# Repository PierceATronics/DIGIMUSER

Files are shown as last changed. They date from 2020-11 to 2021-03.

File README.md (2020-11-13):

# DIGIMUSER
DIGIMUSER is a digital vocal effect processor "stompbox" that applies a variety of real-time signal processing algorithms to alter the voice of a singer. DIGIMUSER takes a (1/4)" mono jack input from a dynamic microphone and outputs through another (1/4)" cable to an amplifier or to additional audio processing equipment. Since the effects applied by DIGIMUSER are performed digitally on a microcontroller, it can be reprogrammed to implement a wide collection of effecus such as filters, delays, distortions, and spatial effects. A standard bypass stomp button enables and disables the effect, a knob selects the type of applied effect, and a slider controls the intensity of the effect.
 
## Project Team Members
David Pierce Walker-Howell (EE), Luke kennard (COMPE), Danielle Stewart (COMPE), Suaod Alhajry (EE), Angel Martinez (COMPE)

## Contribute to this Project
Here are the guidelines to contribute to the project.

#### Branching
The development process for software or hardware must be done in a seperate branch from **main**. Once a software or hardware component is completed a pull request must be made before merging with **main**. The pull request must reviewed and approved before merging to main. 

Here is how to create a new branch off of main. Please use the following naming format for the branch **[Your_name]_[description_of_branch]**

```
Example

//Creates a new branch called "Pierce_I2S_software_development" off of the "main" branch
git checkout -b Pierce_I2S_software_development main
```

#### GIT workflow
Be sure to keep your branch (and the Repository) up-to-date on your local machine by performing pulls often (i.e. be sure to make a pull of the repo prior to making any new edits or commits). Also make sure to commit changes locally often and push those commits to the Github Repository often as well. Below is the typical workflow to follow

```
//Open a git bash or linux terminal and move to the DIGIMUSER project director

//You hop on your computer to begin working on the DIGIMUSER
//First, make sure to pull the repo

git pull

//Next, make sure you are in your development branch

git branch [THE_BRANCH_YOUR_ARE_DEVELOPING_IN]

//Work on coding and designing like on awesome engineer.

//Now you are at a good saving point, and would like to take a break for the day
//Commit your changes with a nice message about what you added/edited

git commit -m "Reworked the communication code for faster data transfer"

//You also want to save your code to the Github repo. So push those commits to the repo

git push origin [THE_BRANCH_YOU_ARE_DEVELOPING_IN]

```

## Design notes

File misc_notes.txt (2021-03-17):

Electrical:
	- The ADC/DAC saturates when a 160mVpp is applied.

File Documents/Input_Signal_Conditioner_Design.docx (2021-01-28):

Input Signal Conditioner (ISC) Circuit Design

David Pierce Walker-Howell

Created: October 27, 2020

1 Description

The Input Signal Conditioner (ISC) is an amplifier and low-pass filter circuit responsible for conditioning the raw microphone signal from a dynamic microphone to be sampled by an Analog-to-Digital Converter (ADC). The circuit comprises of a DC biasing network, non-inverting amplifier, and a 2nd Order Butterworth active low-pass filter (LPF). Presented is the circuit design and specifications to signal the raw microphone signal to be sampled by the Cirrus Logic Inc. CS5343-CZZ Sigma-Delta ADC.

2 Design

2.1 Sallen-Key Low Pass Filter Design

A lowpass filter is designed to condition the frequency response of the microphone prior to sampling of the ADC. Typically, a lowpass filter is used as an anti-aliasing filter for the ADC to ensure no frequency components greater than the Nyquist frequency (Fs / 2) are sampled (which would result in signal aliasing). However, since the design uses a Sigma-Delta ADC with a digital internal anti-aliasing filter, the filter designed for this board is not specifically targeted for anti-aliasing. The lowpass filter design for the Input Signal Conditioner is primarily to cutoff frequencies outside the expected vocal range of a singer. Thus, the cutoff frequency is set to 15KHz, which is a common cutoff frequency estimate for most dynamic microphones. In this design, a Butterwork Sallen-Key lowpass filter is chosen for a variety of reasons [Discuss those here].

There are two critical parameters to consider for selecting an Op-amp for the Sallen-Key LPF: 1) Gain Bandwidth Product (GBWP), 2) Slew Rate. The closed-loop bandwidth of the amplifier must be at least 100 times greater than the passband (or cutoff) frequency of the filter. Thus, the minimum GBWP is calculated as

GBWP_(min) =100*A*f_c =100*1*15K=1.5MHz

The Slew Rate is related to the internal circuitry of the Op-amp and determines how fast the output voltage or current can change. Ideally, the slew rate, measured in volts per microseconds, should be relatively high. The minimum slew rate is calculated based on the cutoff frequency and peak-to-peak output voltage of the amplifier. The minimum slew rate is calculated as

SR_(min) =2πV_(out-pp) f_c =2π(1.0)(15K)=0.09 V/(μs)

Based on the Op-amp requirements, the Microchip MCP6271 rail-to-rail, single-supply Op-amp is chosen.

Specification | Designator | Value
Filter Type | N/A | Butterworth
Configuration | N/A | Sallen-Key
Order | N | 2
Passband Frequency | Fc | 15KHz
DC Gain | A | 1 V/V
Min. GBWP | GBWP_MIN | 1.5MHz
Min. Slew Rate | SR_MIN | 0.09 V / (us)

The design of the lowpass Sallen-Key filter was generated by the Microchip FilterLab® software. The software provides the 1% tolerance resistance and capacitance values to obtain a realistic, implementable filter design.

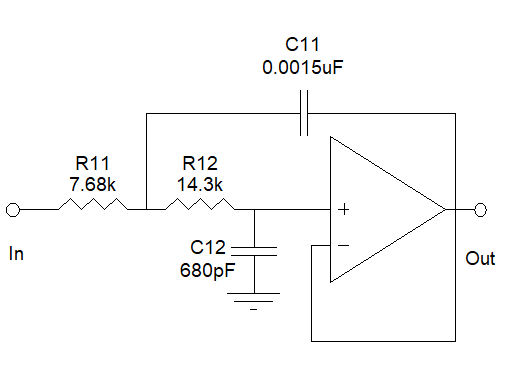
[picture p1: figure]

Figure 1- Sallen-Key, Butterworth, LPF generated by Microchip FilterLab design software (Fc=15KHz).

The designed filter was the simulated in LTSpice with the corresponding MCP6271 Op-amp spice parameters.

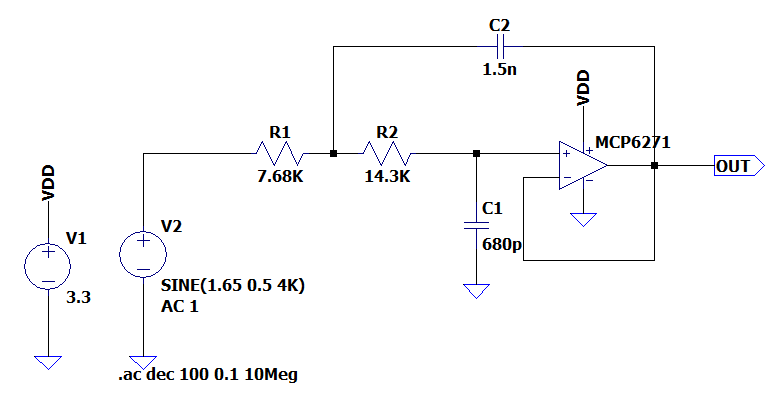
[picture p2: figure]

Figure 2 - LTSpice simulation schematic of LPF.

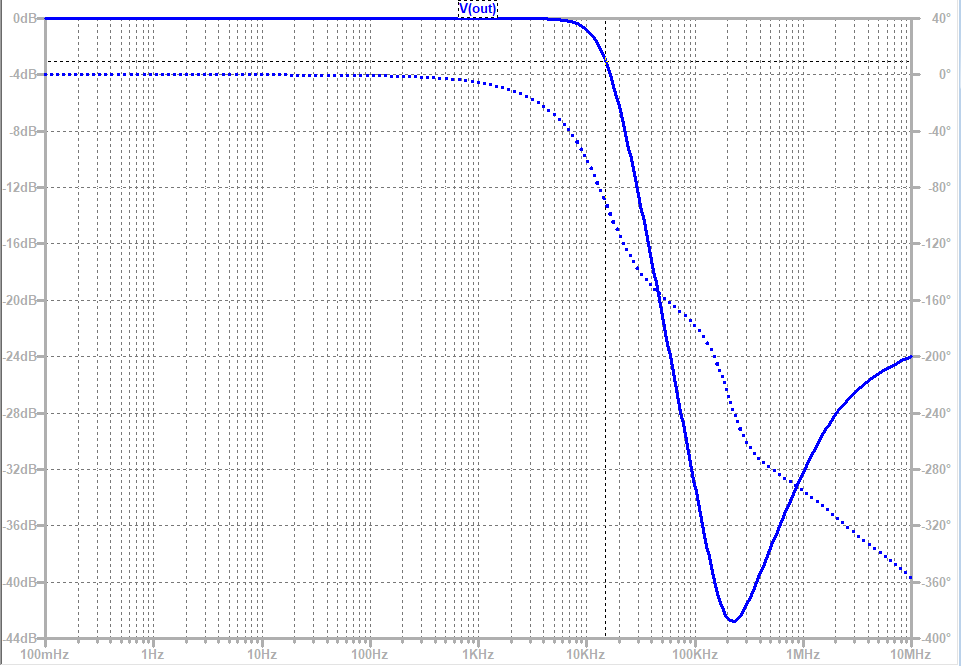
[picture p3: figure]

Figure 3- LTSpice simulated LPF frequency response.

Figure 3 shows the expected magnitude and phase response of the filter. Analyzing the magnitude response shows flat 0dB gain for the passband frequencies and -20dB per decade attenuation after the passband. The expected frequency range of the microphone signal will maintain most of the energy from approximately 50Hz to 2KHz. In this frequency range, it is observed there is a nearly constant group delay (linear phase) as desired.

2.2 Amplifier Design

The raw signal from the microphone is a small signal in the order of tens of millivolts. From initial measurements of a PDMIC58 Pyle Moving Coil Dynamic Handheld Microphone, the maximum raw signal at singing volume is approximately 100mV. This raw signal needs to be amplified and biased for sampling by the ADC.

The ADC chosen is the Cirrus Logic Inc. CS5343-CZZ Sigma-Delta ADC, which provides 24-bit conversion and an internal digital anti-aliasing filter. The datasheet for the device provides suggested analog input signal conditioning. The source impedance (impedance seen from the ADC) should be less than or equal to 2.5KΩ to achieve optimal THD+N performance. The magnitude of the incoming signal to the ADC needs to be less than or equal to the full-scale input voltage of the device. With the ADC operating at 3.3V, the full-scale input voltage range is defined as

V_(fs-pp) =0.568⋅VA=0.568⋅3.3 = 1.874V .

It is important to note the analog input pins of the ADC expects zero DC bias. Thus, the voltage at the input shall be within ±0.937V . The desired gain of the amplifier is calculated as

A_(amp) = (0.937V)/(0.080V)≈12.00V/V=21.6dB

Since the entirety of the design (all PCBs) are powered from a single supply voltage of 3.3V, the analog signal propagating through the Op-amp based amplifier and filter needs to be DC biased to be in the range 0V – 3.3V. Therefore, the input signal of the microphone is DC biased at (V_(DD))/2=1.65V .

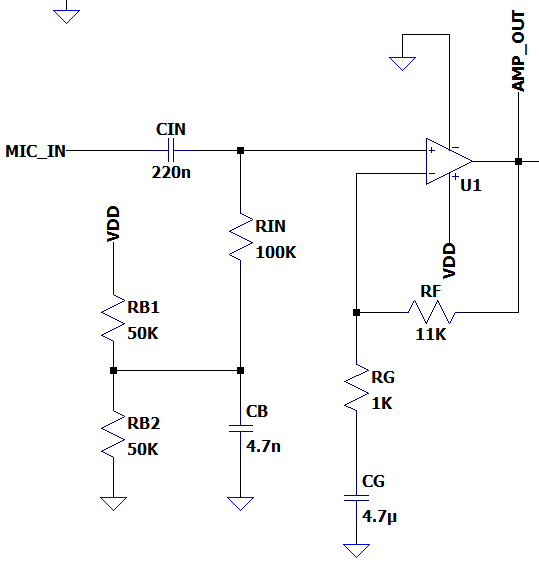
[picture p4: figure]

Figure 4 - Input signal conditioner amplifier

The non-inverting amplifier configuration shown in Figure 4 applies the 1.65V DC bias and amplifies the analog components of the microphone signal by 21.6dB. The input capacitor C_(in) removes any DC components from the raw microphone signal. The DC biasing network composed of R_(B1) ,R_(B2) ,C_b , and R_(in) applies the 1.65V DC bias and acts as a high-pass filter with respect to the microphone input, but a low-pass filter with respect to the V_(DD) input used to set the DC bias value. The primary reason for the addition of C_B is to filter out any analog noise from the power supply of V_(DD) . Ideally, V_(DD) should come from a low-noise voltage regulator and therefore not be of concern. However, if V_(DD) is noisy and not well regulated, the capacitor C_B will filter out any analog frequencies. The AC analysis of the biasing network (with respect to the microphone input) is analyzed to show the frequency response to the incoming microphone signal. A high-pass filter with cutoff-frequency in the tens of volts range is desired since vocal signal are nominally above 80Hz. The network with respect to the microphone input gives the transfer function

H_(bias) (s)=(V_(amp-in+) (s))/(V_(mic-in) (s))=(Z_1 +Z_(3||4))/(Z_1 +Z_2 +Z_(3||4)) .

Z_1 =R_(in) Z_3 =[R_(B1) ||R_(B2) ] Z_4 =1/(C_b s) Z_(3||4) =[Z_3 ||Z_4 ] .

The feedback network of the amplifier, composed of R_f , R_g , and C_g , provides the high passband gain of A_(amp) =12V/V . The capacitor C_g ensures only analog signal components are amplified, and the DC bias signal component is not amplified. The closed-loop transfer function is given as

H_(cl) (s)=(V_(amp-out) (s))/(V_(amp-in) (s))=((R_g +R_f )C_g s + 1)/(R_g C_g s+1)

The total frequency response H_(amp) (s) of the amplifier is given as

H_(amp) (s) = (V_(amp-out) (s))/(V_(mic-in) (s))=H_(bias) (s)H_(cl) (s)

The magnitude frequency response of H_(amp) (s) , with component values shown in Figure 4 , is shown in Figure 5. The cutoff frequency of the amplifier is approximately 35Hz.

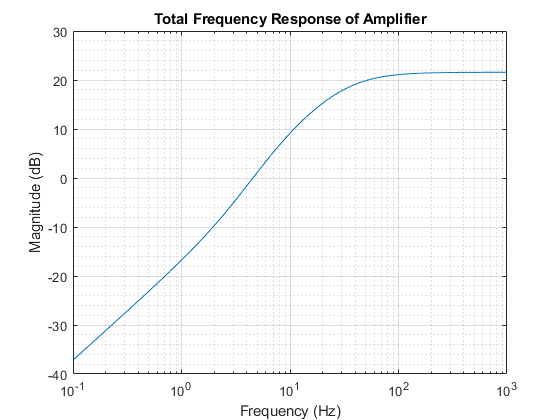
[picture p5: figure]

Figure 5 - Total Frequency response of amplifier

2.3 Combining the Amplifier and Filter

The amplifier and Sallen-key low pass filter are cascaded in series to complete the analog input signal conditioning of the microphone signal for sampling by the ADC. The final design is simulated and verified in LTSpice. It is important to note that the output of the Input Signal Conditioner is at the output of the Sallen-Key lowpass filter. Thus the Input Signal Conditioner does not perform the final step of removing the 1.65V DC bias before feeding into the ADC. This required step is done on the external board hosting the ADC. Therefore, the output of the Input Signal Conditioner is an amplified and low pass filtered version of the microphone signal with 1.65V DC bias.

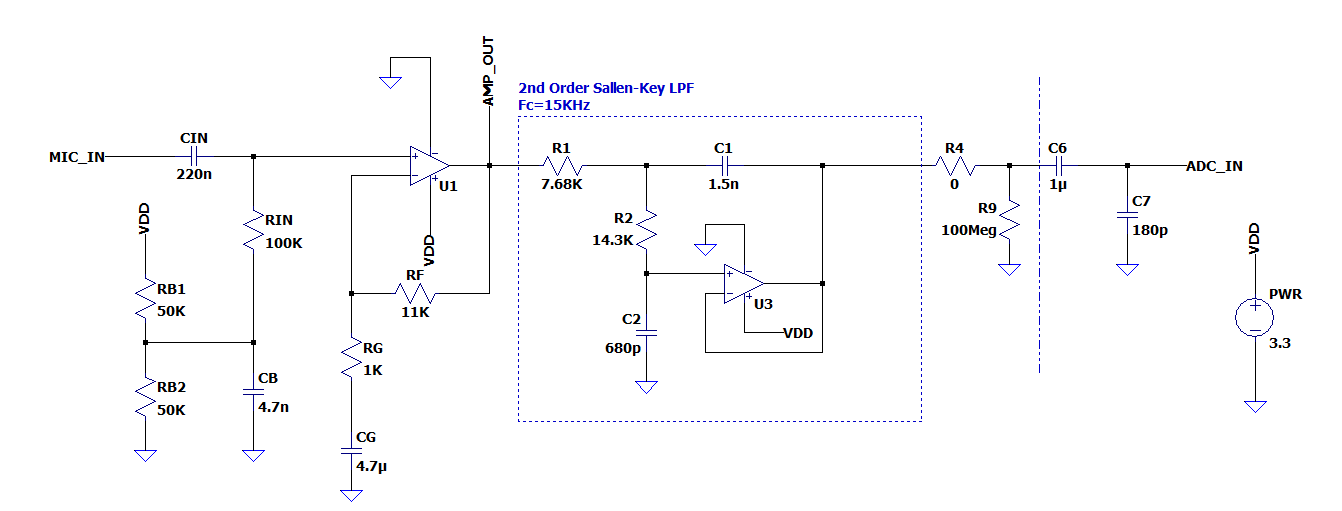
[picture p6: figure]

Figure 6 - Input signal conditioner (Amplifier + LPF) LTSpice schematic.

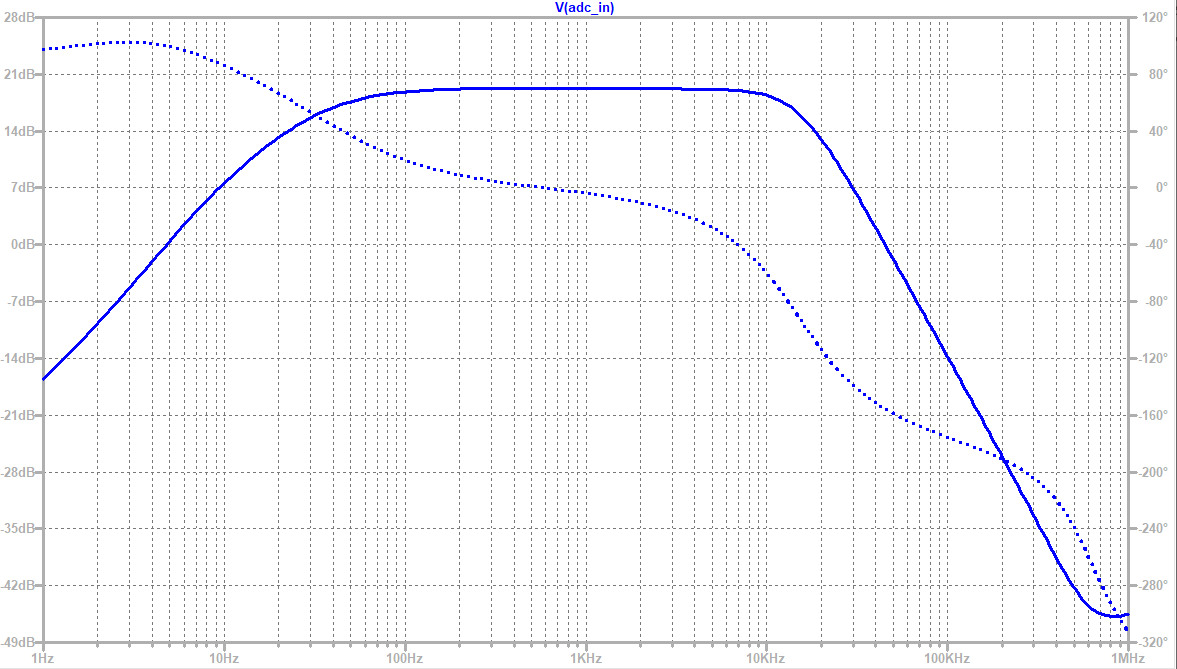
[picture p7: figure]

Figure 7- Frequency response (AC analysis) of Input Signal Conditioner.

Figure 7 is the simulated (expected) frequency response of the Input Signal Conditioner board design. Table 1 summarizes the specifications of the design.

Specification | Designator | Value (Typ.)
Low Freq. Cutoff | Fcl | 35Hz
High Freq. Cutoff | Fch | 15KHz
Passband Gain | A | 21dB
Output DC bias | VDC | 1.65V

Table 1- Input Signal Conditioner Specifications

Prototype

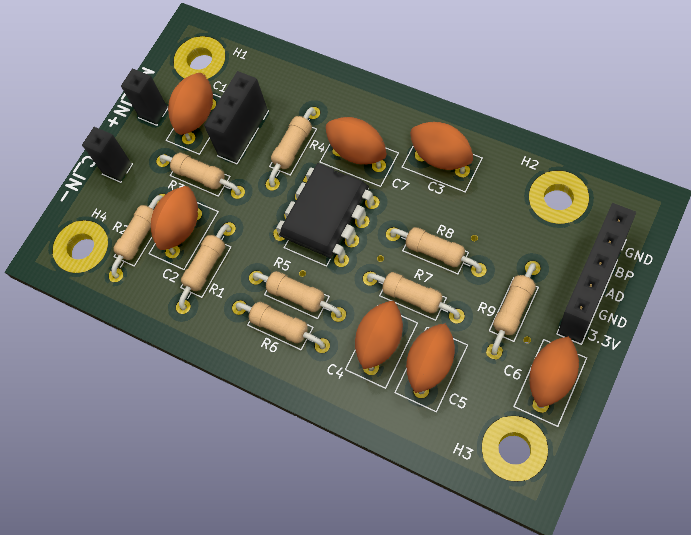
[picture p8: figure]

Figure 8 - PCB design of ISC using KiCad.

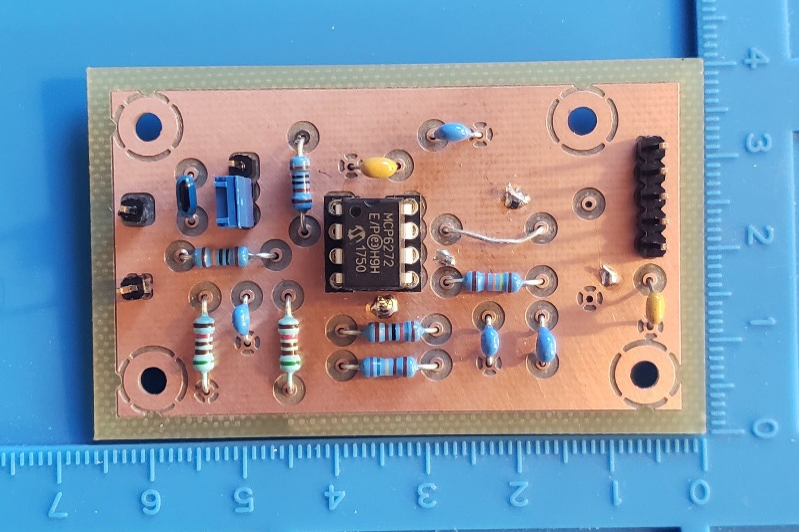
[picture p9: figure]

Figure 9 - Milled and Assembled prototype of the ISC.

Validations

Specification | Designator | Value (Typ.) | Specification Met
Low Freq. Cutoff | Fcl | 35Hz | YES
High Freq. Cutoff | Fch | 15KHz | YES
Passband Gain | A | 21.6 dB | YES – 21.6 dB
Output DC bias | VDC | 1.65V | YES

Validations of the ISC were performed using a function generator for the input signal and an oscilloscope for measuring the output signal. The input signal is a 25mV amplitude sine wave with 0V DC bias. The frequency of the signal was varied to validate the frequency response of the circuit. The input signal matches the approximate expected microphone signal in amplitude.

The oscilloscope plots below present the AC coupled input and output signals of the ISC. The input signal on the ISC is measured at 20mV / div and the output signal is measured at 200 mV / div.

Figure 10 - 100Hz sine wave input (Yellow). The output signal (Blue) has an amplitude of 520mV. The gain at 100Hz is thus A=10.4 V/V.

Figure 11 - 440Hz sine wave input (Yellow). The output signal (Blue) has an amplitude of 610mV. The gain at 440Hz is thus A=12.2V/V.

Figure 12 -1KHz sine wave input (Yellow). The output signal (Blue) has an amplitude of 600mV. The gain at 1KHz is thus A=12.0V/V.

Figure 13- 15KHz sine wave input (Yellow). The output signal (Blue) has an amplitude of 450mV. The gain at 15KHz is thus A=9V/V. 15KHz is the desired -3dB cutoff for this filter circuit, thus that figure is approximately met with a measured -2.5dB attenuation at 15KHz.

Figure 14 - 20KHz sine wave input (Yellow). The output signal (Blue) has an amplitude of 300mV. The gain at 20KHz is thus A=6.0V/V.

Figure 15 - 40KHz sine wave input (Yellow). The output signal (Blue) has an amplitude of 110mV. The gain at 40KHz is thus A=2.2V/V.

Citations

ADN003 “Select the Right Operational Amplifier for your Filtering Circuits”, Bonnie C. Baker, Microchip Technology Inc.

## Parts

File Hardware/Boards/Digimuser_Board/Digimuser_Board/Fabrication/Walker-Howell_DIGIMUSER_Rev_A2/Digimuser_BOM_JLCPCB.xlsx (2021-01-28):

Comment | Designator | Footprint | LCSC Part #（optional）
22nF | C1 | 0805_C | C1729 | x
51KΩ | R1, R2 | 0805_R | C17737 | x
100KΩ | R6 | 0805_R | C17407 | x
4.7nF | C2 | 0805_C | C1744 | x
4.7uF | C3 | 0805_C | C1779 | x
1KΩ | R9 | 0805_R | C17513 | x
11KΩ | R10 | 0805_R | C17429 | x
100nF | C4, C10, C11, C14, C15, C16, C23 | 0805_C | C49678 | x
7.68KΩ | R11 | 0805_R | C30041 | x
14.3KΩ | R12 | 0805_R | C17456 | x
680pF | C5 | 0805_C | C53150 | x
1.5nF | C6 | 0805_C | C1717 | x
10KΩ | R3, R4, R5, R7, R8, R15, R16, R17 | 0805_R | C17414 | x
1uF | C8, C18, C19, C20, C21, C26 | 0805_C | C28323 | x
180pF | C17, C27 | 0805_C | C62914 | x
3.3uF | C7, C9, C12 | 0805_C | C159775 | x
470Ω | R18, R19 | 0805_R | C17710 | x
3.3nF | C24, C25 | 0805_C | C53175 | x
0.33uF | C22 | 0805_C | C1740 | x

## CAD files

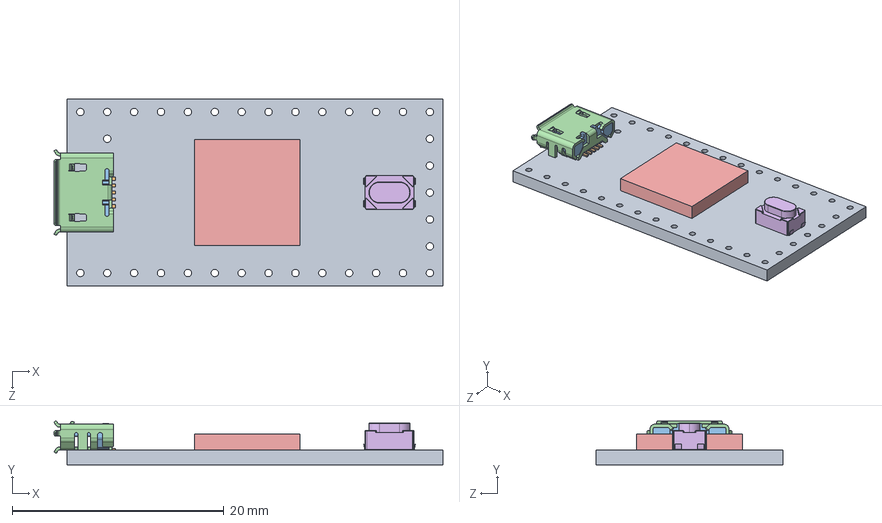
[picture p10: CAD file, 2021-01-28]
Hardware/Project_Library/teensy.pretty-master/teensy.pretty-master/Teensy_4.0_Assembly.STEP
36.8 x 4.12 x 17.7 mm
Teensy_4.0_PCB
Micro USB-B Female 5Pin SMD
NXP iMXRT1062
SKRPACE010 v4

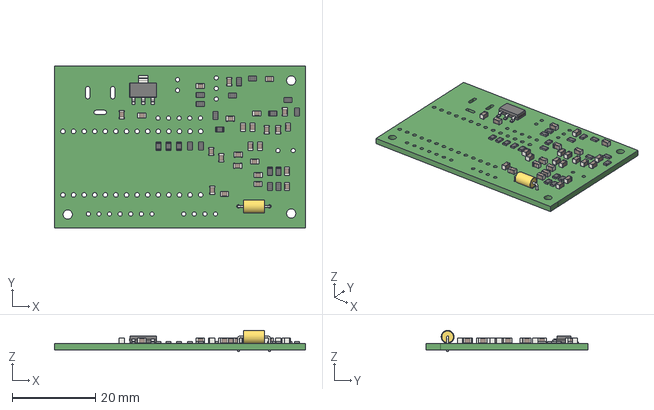
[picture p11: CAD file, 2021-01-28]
Hardware/Boards/Digimuser_Board/Digimuser_Board/Fabrication/Digimuser_Board.step
60.2 x 38.7 x 5.10 mm

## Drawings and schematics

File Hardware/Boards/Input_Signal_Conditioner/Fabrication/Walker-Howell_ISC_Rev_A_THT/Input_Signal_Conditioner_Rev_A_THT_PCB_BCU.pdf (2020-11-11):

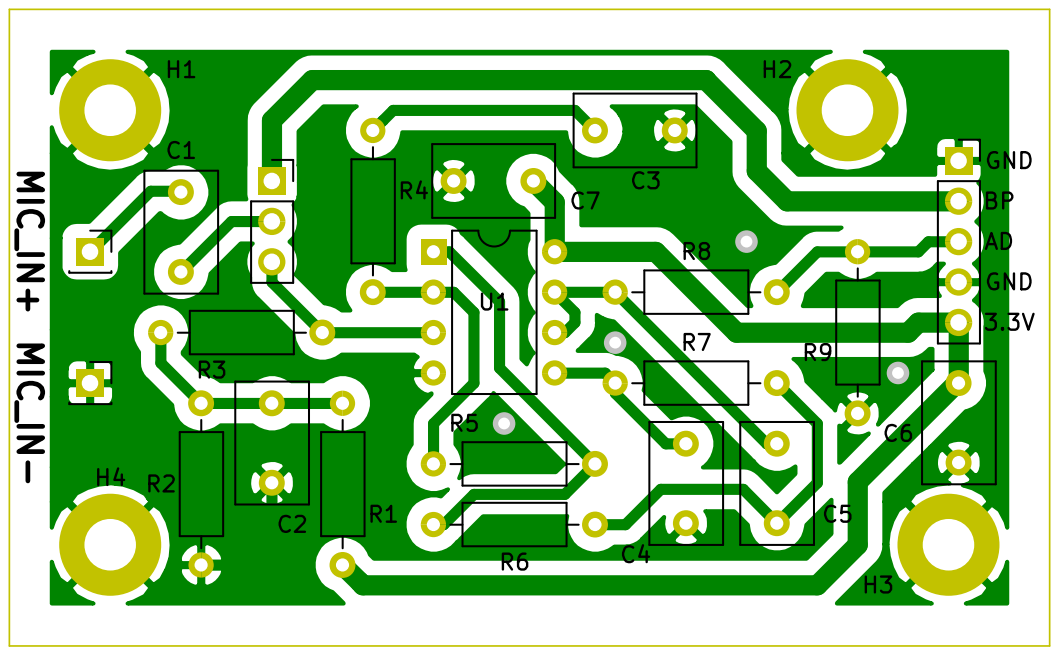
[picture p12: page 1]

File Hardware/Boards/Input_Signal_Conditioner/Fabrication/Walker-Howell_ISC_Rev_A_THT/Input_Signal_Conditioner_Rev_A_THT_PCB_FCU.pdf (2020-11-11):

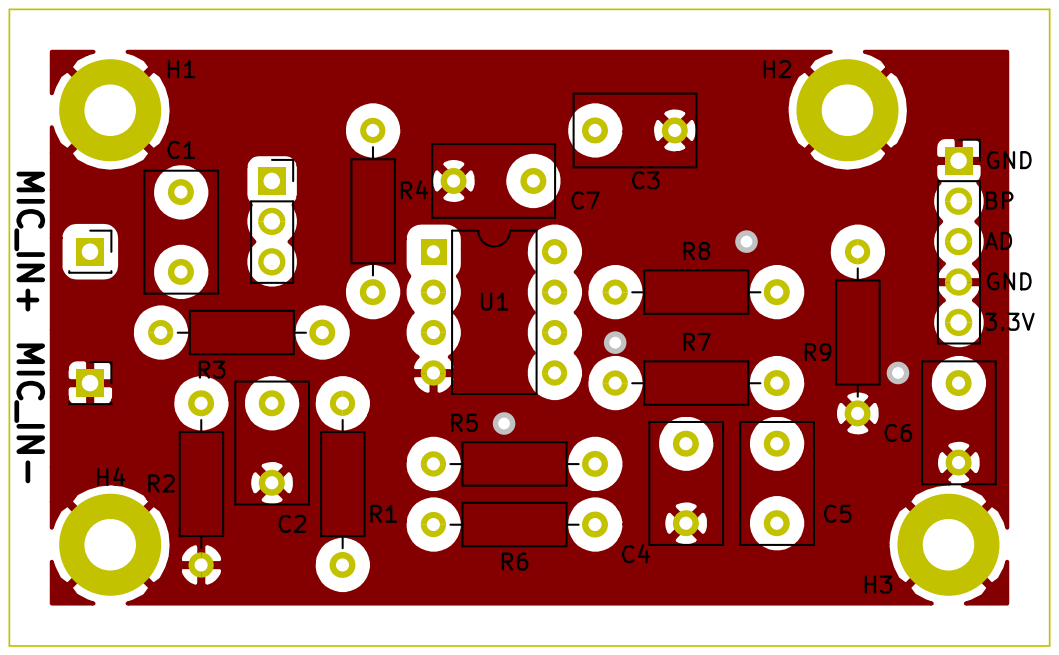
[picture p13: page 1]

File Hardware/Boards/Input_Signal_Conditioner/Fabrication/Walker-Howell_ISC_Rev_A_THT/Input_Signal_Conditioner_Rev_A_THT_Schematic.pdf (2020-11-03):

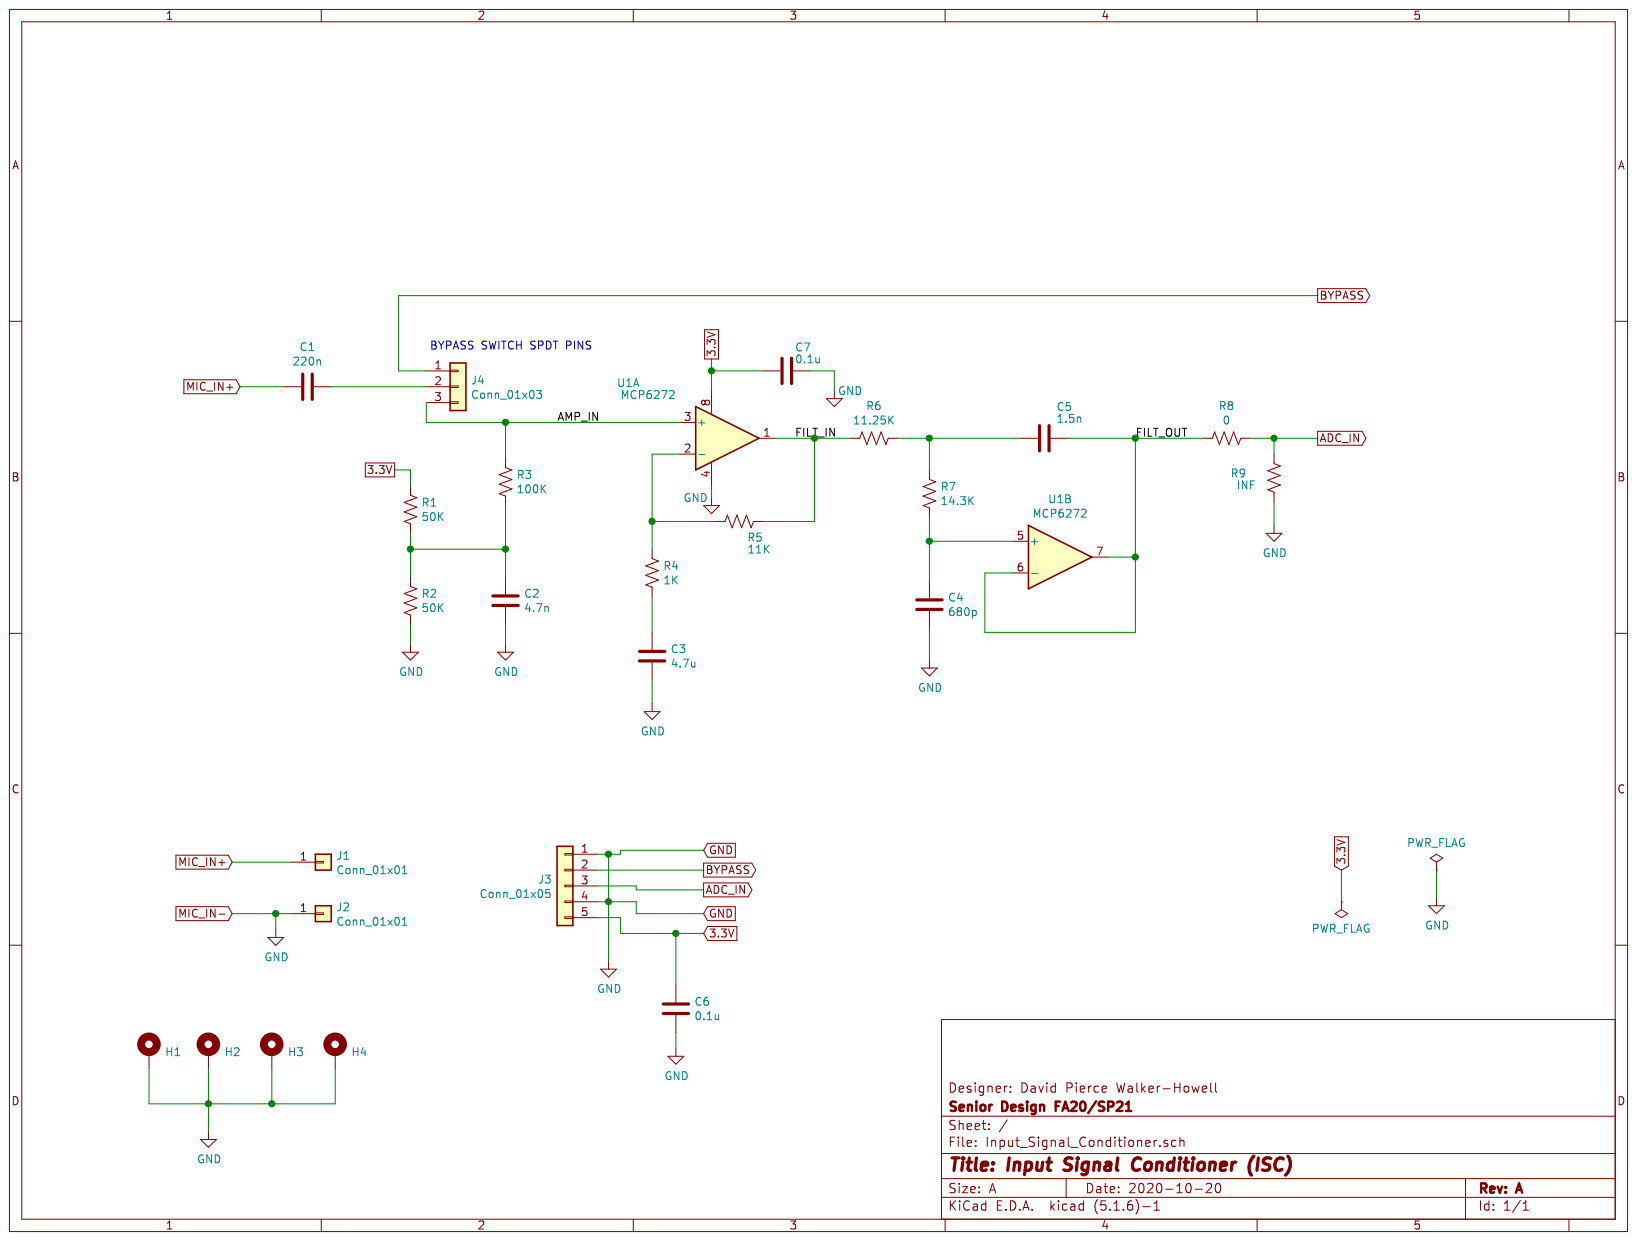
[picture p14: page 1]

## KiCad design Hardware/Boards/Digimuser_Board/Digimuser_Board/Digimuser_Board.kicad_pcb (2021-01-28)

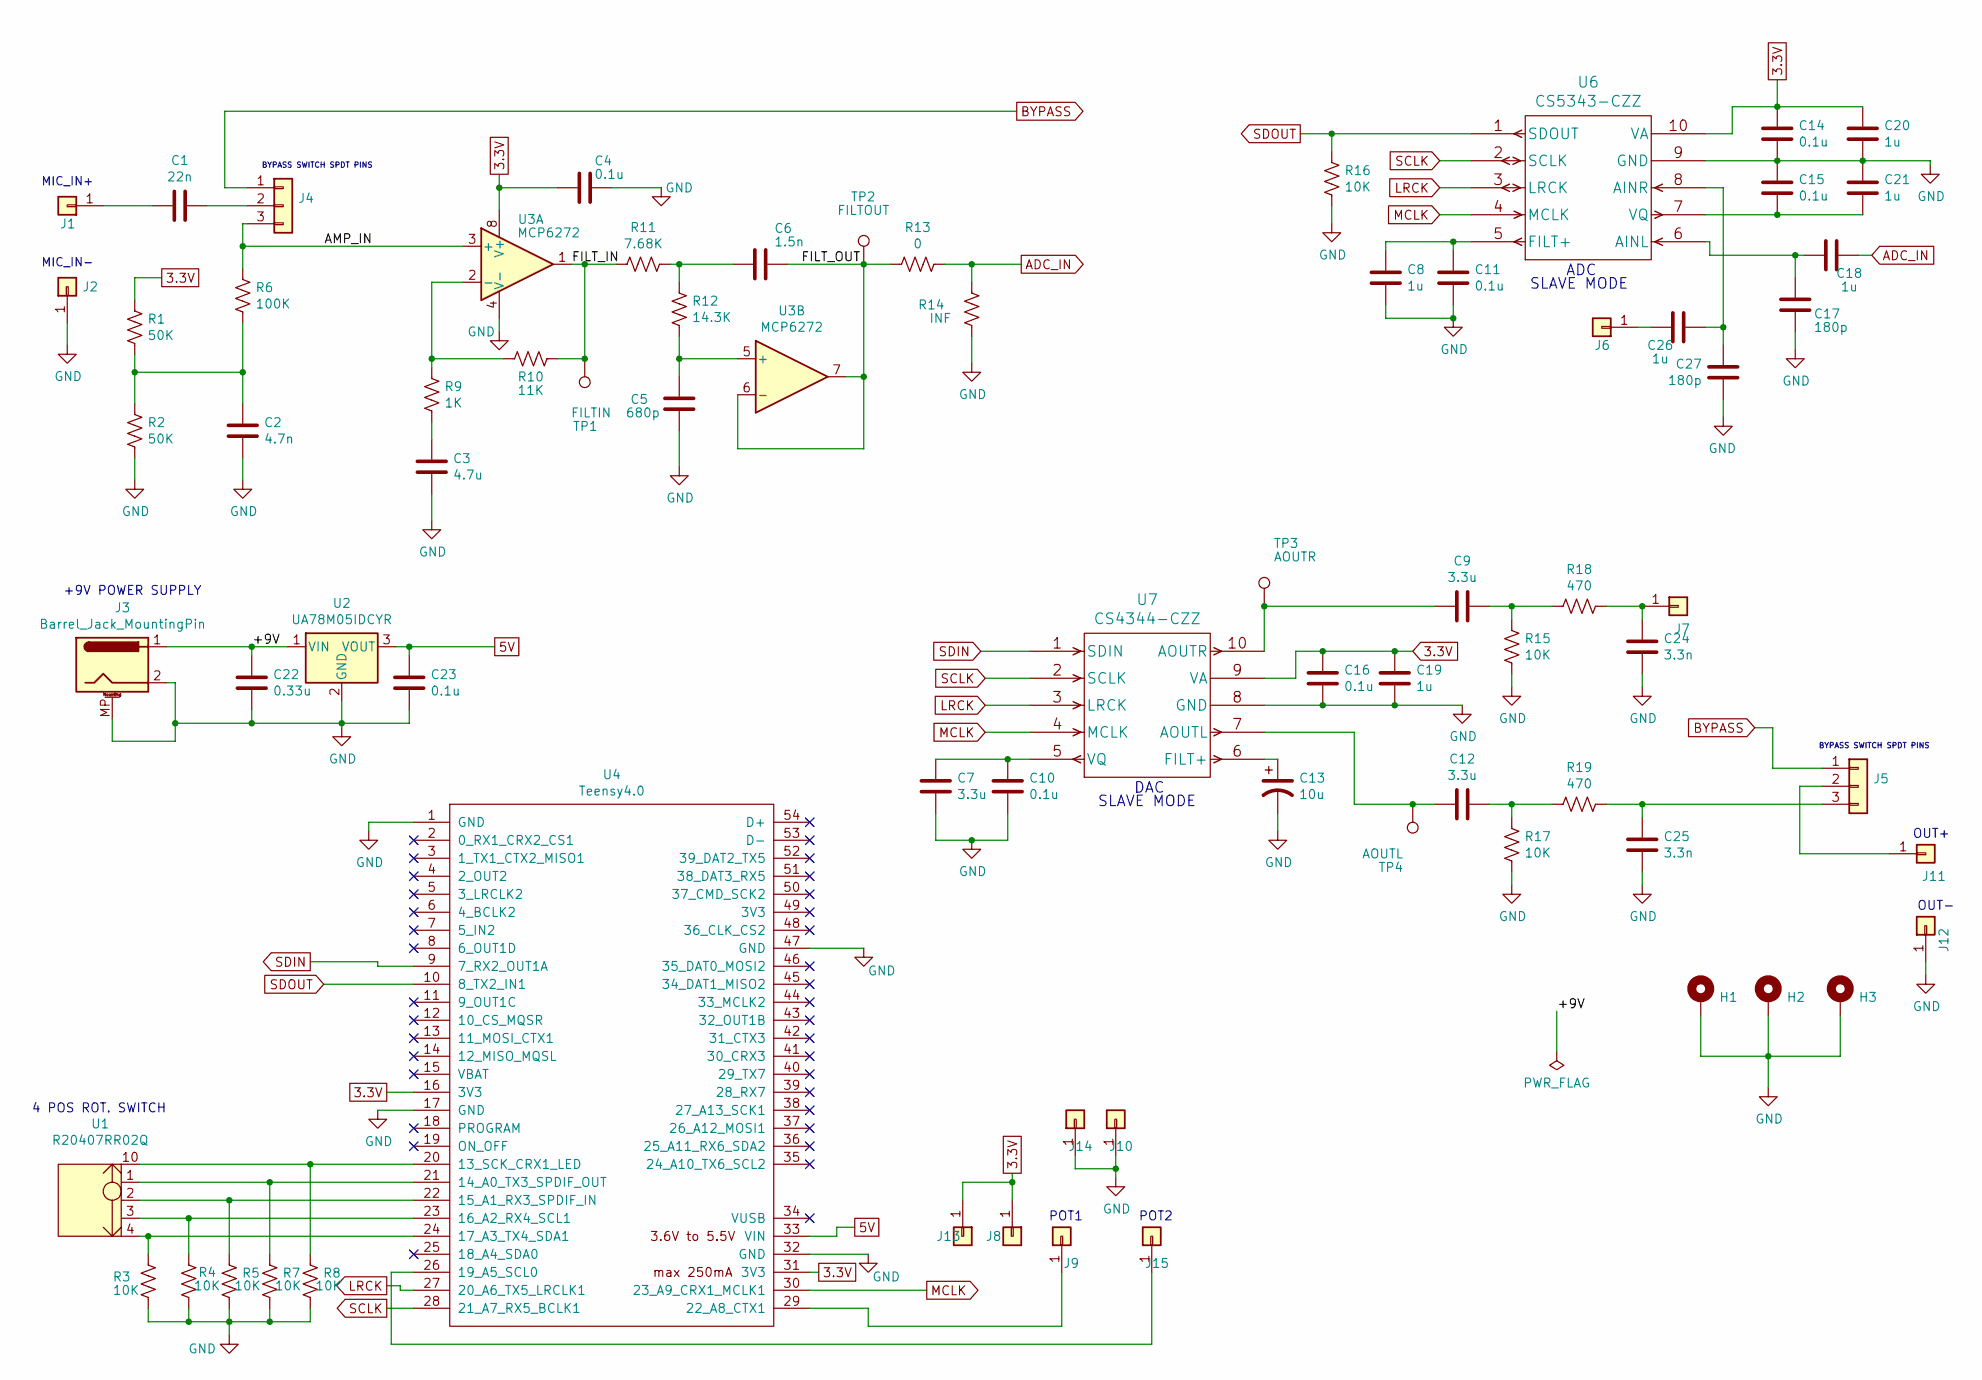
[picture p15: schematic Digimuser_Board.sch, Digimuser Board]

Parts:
C1: 22n; C_0805_2012Metric
C2: 4.7n; C_0805_2012Metric
C3: 4.7u; C_0805_2012Metric
C4, C10, C11, C14, C15, C16, C23: 0.1u; C_0805_2012Metric
C5: 680p; C_0805_2012Metric
C6: 1.5n; C_0805_2012Metric
C7, C9, C12: 3.3u; C_0805_2012Metric
C8, C18, C19, C20, C21, C26: 1u; C_0805_2012Metric
C13: 10u; C_Axial_L5.1mm_D3.1mm_P7.50mm_Horizontal
C17, C27: 180p; C_0805_2012Metric
C22: 0.33u; C_0805_2012Metric
C24, C25: 3.3n; C_0805_2012Metric
H1, H2, H3: MountingHole_Pad; MountingHole_2.2mm_M2_Pad
J1, J2, J6, J7, J8, J9, J10, J11, J12, J13, J14, J15: Conn_01x01; PinHeader_2.54mm_1x01_P2.54mm
J3: Barrel_Jack_MountingPin; BarrelJack_Horizontal
J4, J5: Conn_01x03; PinHeader_2.54mm_1x03_P2.54mm
R1, R2: 50K; R_0805_2012Metric
R3, R4, R5, R7, R8, R15, R16, R17: 10K; R_0805_2012Metric
R6: 100K; R_0805_2012Metric
R9: 1K; R_0805_2012Metric
R10: 11K; R_0805_2012Metric
R11: 7.68K; R_0805_2012Metric
R12: 14.3K; R_0805_2012Metric
R13: 0; R_0805_2012Metric
R14: INF; R_0805_2012Metric
R18, R19: 470; R_0805_2012Metric
TP1: FILTIN; TestPoint_Keystone_5019_Minature
TP2: FILTOUT; TestPoint_Keystone_5019_Minature
TP3: AOUTR; TestPoint_Keystone_5019_Minature
TP4: AOUTL; TestPoint_Keystone_5019_Minature
U1: R20407RR02Q
U2: UA78M05IDCYR; SOT-223-3_TabPin2
U3: MCP6272; SOIC127P600X175-8N
U4: Teensy4.0; Teensy40_HAT
U6: CS5343-CZZ
U7: CS4344-CZZ

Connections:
3.3V: C4.2, C14.1, C16.1, C19.1, C20.1, J8.1, J13.1, R1.1, U3.8 (V+), U4.16 (3V3), U4.31 (3V3), U6.10 (VA), U7.9 (VA)
5V: C23.1, U2.3 (VOUT), U4.33 (VIN)
/+9V: C22.1, J3.1, U2.1 (VIN)
/AMP_IN: J4.3, R6.1, U3.3 (+)
/FILT_IN: R10.1, R11.2, TP1.1, U3.1
/FILT_OUT: C6.1, R13.2, TP2.1, U3.6 (-), U3.7
ADC_IN: C18.1, R13.1, R14.2
BYPASS: J4.1, J5.1
GND: C2.2, C3.2, C4.1, C5.2, C7.2, C8.2, C10.2, C11.2, C13.2, C14.2, C15.1, C16.2, C17.2, C19.2, C20.2, C21.1, C22.2, C23.2, C24.2, C25.2, C27.2, H1.1, H2.1, H3.1, J2.1, J3.2, J3.MP (MountPin), J10.1, J12.1, J14.1, R2.2, R3.2, R4.2, R5.2, R7.2, R8.2, R14.1, R15.2, R16.2, R17.2, U2.2 (GND), U3.4 (V-), U4.1 (GND), U4.17 (GND), U4.32 (GND), U4.47 (GND), U6.9 (GND), U7.8 (GND)
LRCK: U4.27 (20_A6_TX5_LRCLK1), U6.3 (LRCK), U7.3 (LRCK)
MCLK: U4.30 (23_A9_CRX1_MCLK1), U6.4 (MCLK), U7.4 (MCLK)
unnamed: C1.1, J4.2
unnamed: C1.2, J1.1
unnamed: C2.1, R1.2, R2.1, R6.2
unnamed: C3.1, R9.2
unnamed: C5.1, R12.2, U3.5 (+)
unnamed: C6.2, R11.1, R12.1
unnamed: C9.1, R15.1, R18.2
unnamed: C9.2, TP3.1, U7.10 (AOUTR)
unnamed: C7.1, C10.1, U7.5 (VQ)
unnamed: C8.1, C11.1, U6.5 (FILT+)
unnamed: C12.1, R17.1, R19.2
unnamed: C12.2, TP4.1, U7.7 (AOUTL)
unnamed: C13.1, U7.6 (FILT+)
unnamed: C15.2, C21.2, U6.7 (VQ)
unnamed: C17.1, C18.2, U6.6 (AINL)
unnamed: C24.1, J7.1, R18.1
unnamed: C25.1, J5.3, R19.1
unnamed: C26.1, J6.1
unnamed: C26.2, C27.1, U6.8 (AINR)
unnamed: J9.1, U4.29 (22_A8_CTX1)
unnamed: J5.2, J11.1
unnamed: J15.1, U4.26 (19_A5_SCL0)
unnamed: R3.1, U1.4, U4.24 (17_A3_TX4_SDA1)
unnamed: R4.1, U1.3, U4.23 (16_A2_RX4_SCL1)
unnamed: R5.1, U1.2, U4.22 (15_A1_RX3_SPDIF_IN)
unnamed: R7.1, U1.1, U4.21 (14_A0_TX3_SPDIF_OUT)
unnamed: R8.1, U1.10, U4.20 (13_SCK_CRX1_LED)
unnamed: R9.1, R10.2, U3.2 (-)
SCLK: U4.28 (21_A7_RX5_BCLK1), U6.2 (SCLK), U7.2 (SCLK)
SDIN: U4.9 (7_RX2_OUT1A), U7.1 (SDIN)
SDOUT: R16.1, U4.10 (8_TX2_IN1), U6.1 (SDOUT)

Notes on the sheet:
BYPASS SWITCH SPDT PINS
MIC_IN+
MIC_IN-
ADC
SLAVE MODE
DAC
+9V POWER SUPPLY
4 POS ROT. SWITCH
OUT+
OUT-
POT1
POT2

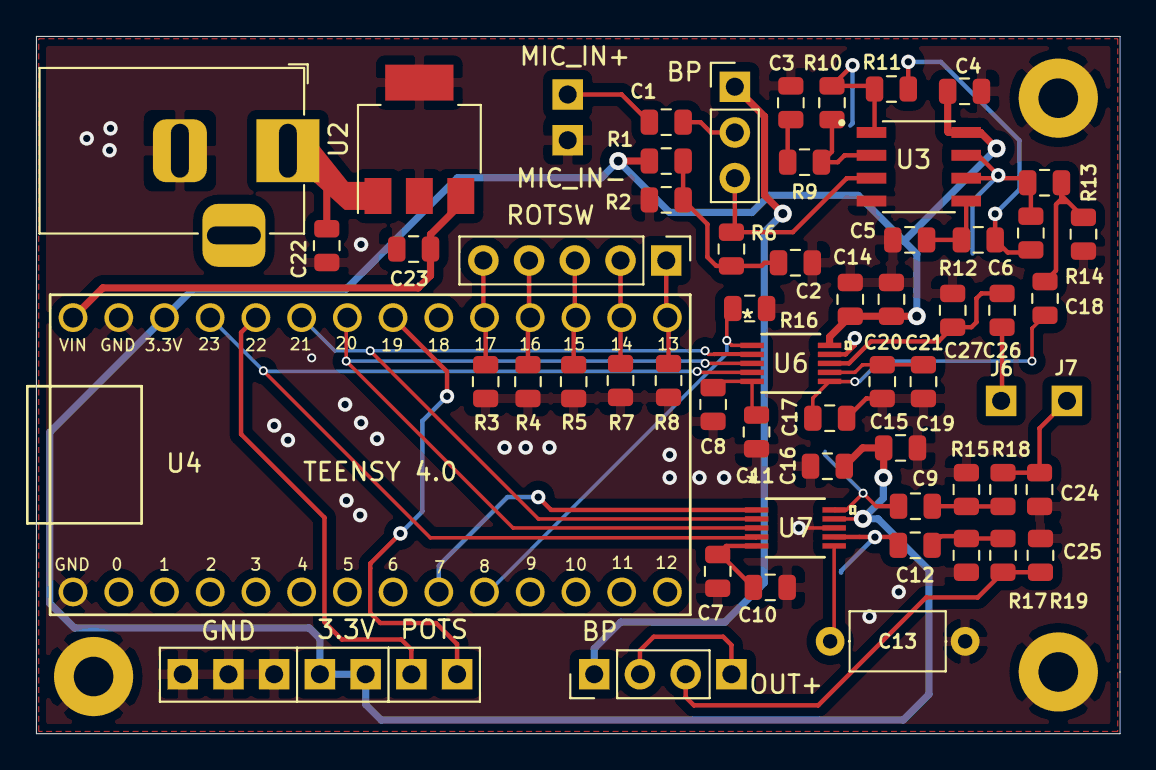
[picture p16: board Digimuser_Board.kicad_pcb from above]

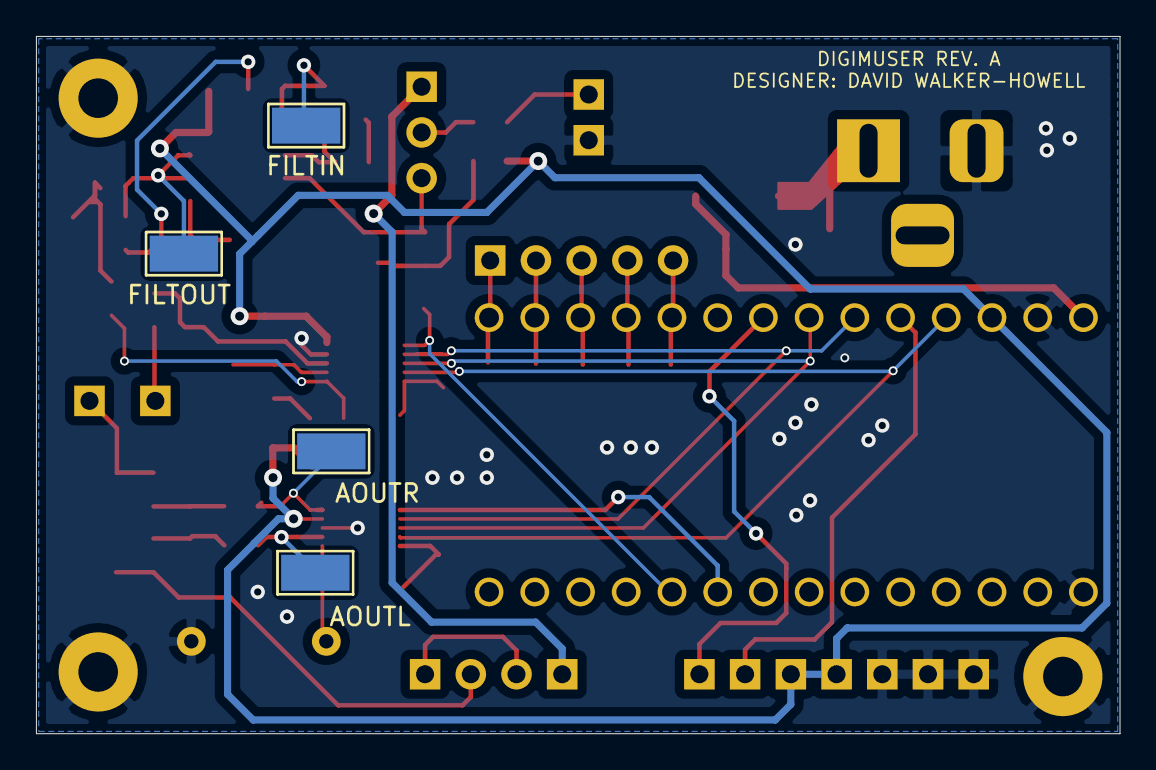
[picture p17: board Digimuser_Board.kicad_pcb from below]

Board: 2 copper layers, 60.2 x 38.7 mm, 74 parts (4 on the bottom side), 42 nets.

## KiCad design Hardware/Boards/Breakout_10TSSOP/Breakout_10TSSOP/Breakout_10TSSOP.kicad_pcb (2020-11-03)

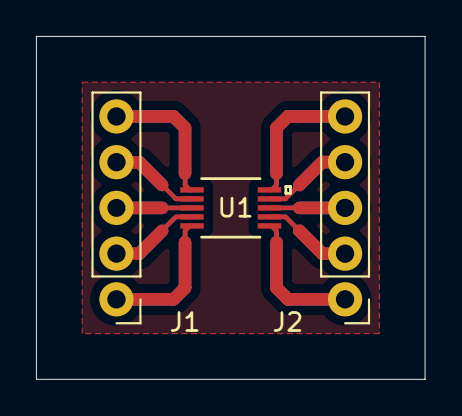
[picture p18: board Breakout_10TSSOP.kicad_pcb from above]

Board: 2 copper layers, 21.6 x 19.0 mm, 4 parts (1 on the bottom side), 10 nets.

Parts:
J1, J2: Conn_01x05_Male; PinHeader_1x05_P2.54mm_Vertical
U1, U1#2: CS5343-CZZ

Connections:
1: J1.5, U1.5, U1#2.1
2: J1.4, U1.4, U1#2.2
3: J1.3, U1.3, U1#2.3
4: J1.2, U1.2, U1#2.4
5: J1.1, U1.1, U1#2.5
6: J2.1, U1.10, U1#2.6
7: J2.2, U1.9, U1#2.7
8: J2.3, U1.8, U1#2.8
9: J2.4, U1.7, U1#2.9
10: J2.5, U1.6, U1#2.10

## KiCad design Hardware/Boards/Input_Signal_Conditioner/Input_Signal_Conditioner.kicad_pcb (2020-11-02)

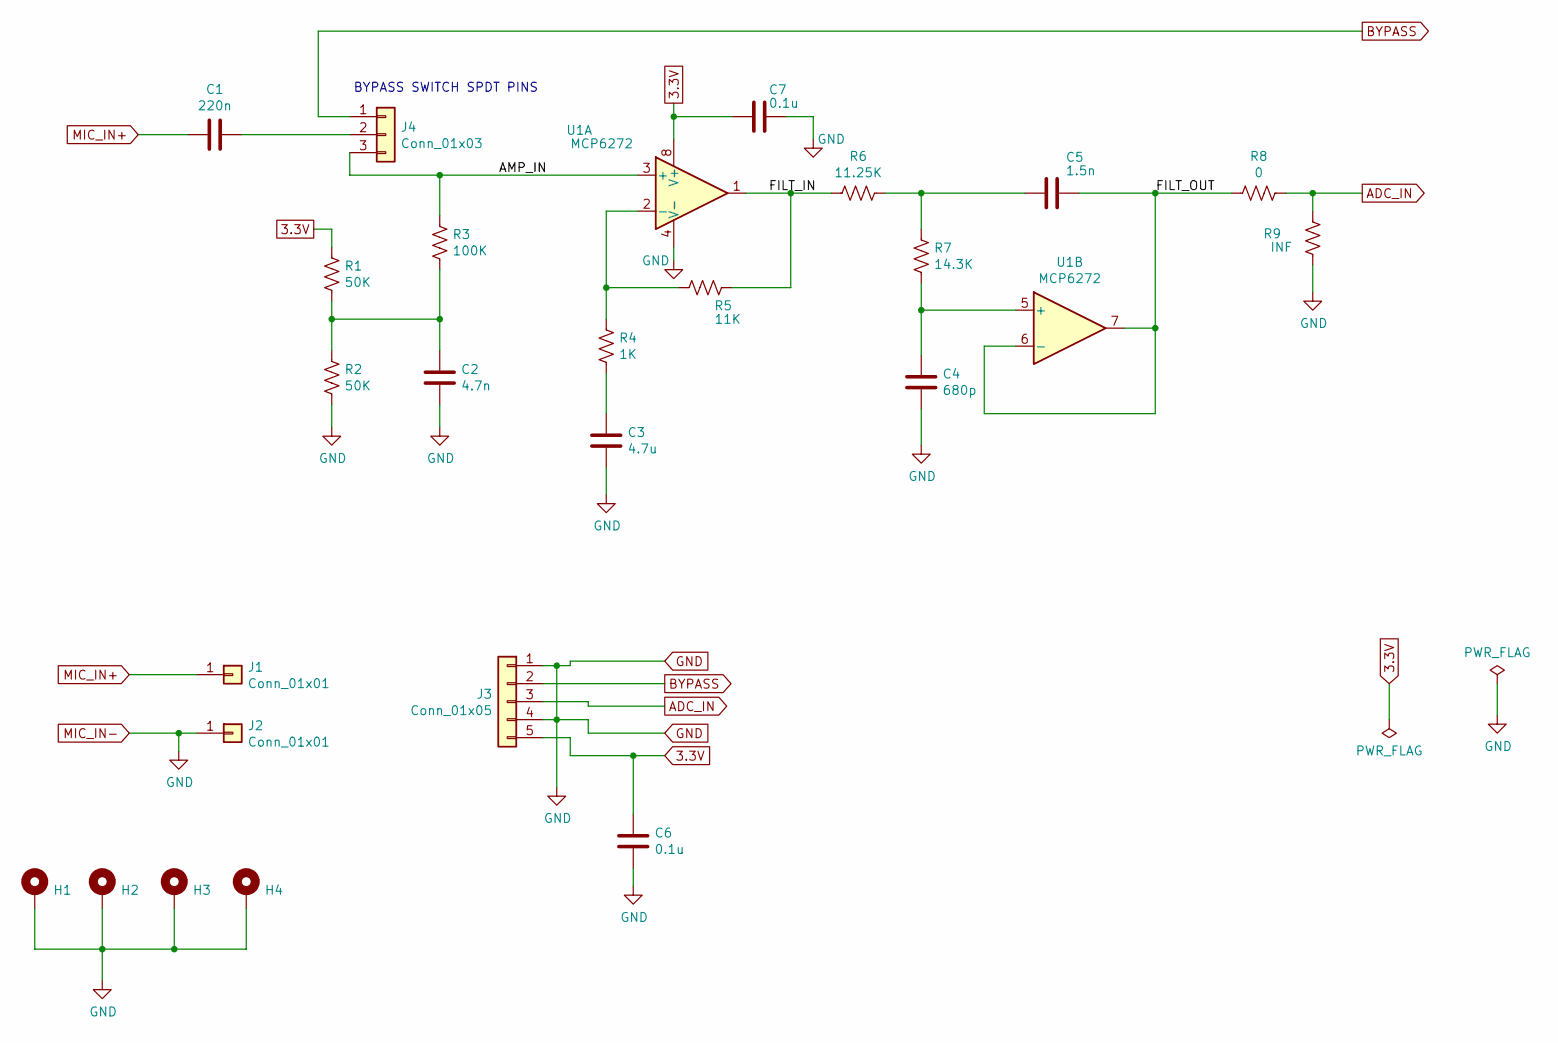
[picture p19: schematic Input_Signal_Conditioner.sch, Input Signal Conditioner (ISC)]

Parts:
C1: 220n; C_Disc_D7.5mm_W4.4mm_P5.00mm
C2: 4.7n; C_Disc_D7.5mm_W4.4mm_P5.00mm
C3: 4.7u; C_Disc_D7.5mm_W4.4mm_P5.00mm
C4: 680p; C_Disc_D7.5mm_W4.4mm_P5.00mm
C5: 1.5n; C_Disc_D7.5mm_W4.4mm_P5.00mm
C6, C7: 0.1u; C_Disc_D7.5mm_W4.4mm_P5.00mm
H1, H2, H3, H4: MountingHole_Pad; MountingHole_3.2mm_M3_Pad
J1, J2: Conn_01x01; PinSocket_1x01_P2.54mm_Vertical
J3: Conn_01x05; PinSocket_1x05_P2.54mm_Vertical
J4: Conn_01x03; PinSocket_1x03_P2.54mm_Vertical
R1, R2: 50K; R_Axial_DIN0207_L6.3mm_D2.5mm_P10.16mm_Horizontal
R3: 100K; R_Axial_DIN0207_L6.3mm_D2.5mm_P10.16mm_Horizontal
R4: 1K; R_Axial_DIN0207_L6.3mm_D2.5mm_P10.16mm_Horizontal
R5: 11K; R_Axial_DIN0207_L6.3mm_D2.5mm_P10.16mm_Horizontal
R6: 11.25K; R_Axial_DIN0207_L6.3mm_D2.5mm_P10.16mm_Horizontal
R7: 14.3K; R_Axial_DIN0207_L6.3mm_D2.5mm_P10.16mm_Horizontal
R8: 0; R_Axial_DIN0207_L6.3mm_D2.5mm_P10.16mm_Horizontal
R9: INF; R_Axial_DIN0207_L6.3mm_D2.5mm_P10.16mm_Horizontal
U1: MCP6272; DIP-8_W7.62mm

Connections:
3.3V: C6.1, C7.2, J3.5, R1.1, U1.8 (V+)
/AMP_IN: J4.3, R3.1, U1.3 (+)
/FILT_IN: R5.1, R6.2, U1.1
/FILT_OUT: C5.1, R8.2, U1.6 (-), U1.7
ADC_IN: J3.3, R8.1, R9.2
BYPASS: J3.2, J4.1
GND: C2.2, C3.2, C4.2, C6.2, C7.1, H1.1, H2.1, H3.1, H4.1, J2.1, J3.1, J3.4, R2.2, R9.1, U1.4 (V-)
MIC_IN+: C1.2, J1.1
unnamed: C1.1, J4.2
unnamed: C2.1, R1.2, R2.1, R3.2
unnamed: C3.1, R4.2
unnamed: C4.1, R7.2, U1.5 (+)
unnamed: C5.2, R6.1, R7.1
unnamed: R4.1, R5.2, U1.2 (-)

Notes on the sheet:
BYPASS SWITCH SPDT PINS

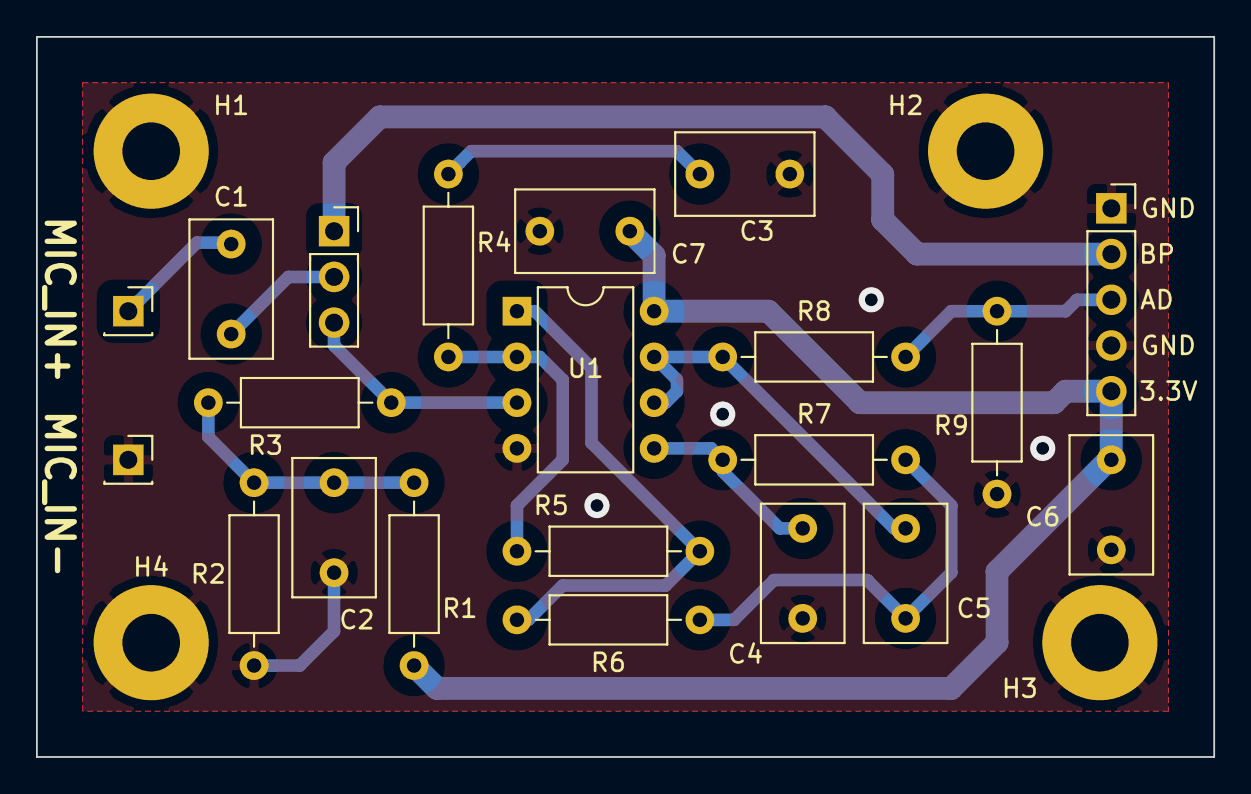
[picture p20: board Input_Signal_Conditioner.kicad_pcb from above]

Board: 2 copper layers, 65.4 x 40.0 mm, 25 parts (0 on the bottom side), 14 nets.

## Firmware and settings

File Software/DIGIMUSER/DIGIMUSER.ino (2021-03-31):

/*
MIT License

Copyright (c) 2020 David Walker-Howell

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
THE SOFTWARE IS PROVIDED "AS IS", WITHOUT WARRANTY OF ANY KIND, EXPRESS OR
IMPLIED, INCLUDING BUT NOT LIMITED TO THE WARRANTIES OF MERCHANTABILITY,
FITNESS FOR A PARTICULAR PURPOSE AND NONINFRINGEMENT. IN NO EVENT SHALL THE
AUTHORS OR COPYRIGHT HOLDERS BE LIABLE FOR ANY CLAIM, DAMAGES OR OTHER
LIABILITY, WHETHER IN AN ACTION OF CONTRACT, TORT OR OTHERWISE, ARISING FROM,
OUT OF OR IN CONNECTION WITH THE SOFTWARE OR THE USE OR OTHER DEALINGS IN THE
SOFTWARE.
 */
#include "Effects.h"

/* CHOOSE THE INPUT DEVICE
 *  INPUT_DEVICE 0 ==> CS5343 ADC
 *  INPUT_DEVICE 1 ==> USB (make sure to change USB Type to Audio under Tools -> USB Typ)e  
 */
#define INPUT_DEVICE 0

const int pot1_pin = A5;
AudioOutputI2S     cs4344_dac;

#if INPUT_DEVICE == 0
  AudioInputI2S      input_device;
#else
  AudioInputUSB      input_device;
#endif

//  Initialize the reverb effect.
Reverb reverb;

//Connect the output of the ADC to the input of the digital amplifier fx
AudioConnection   connection_1(input_device, 0, reverb, 0);
//Connect the output of the amplifier fx to the input of the DAC.
AudioConnection   connection_2(reverb, 0, cs4344_dac, 0);

void setup(){

  Serial.begin(115200);
  AudioMemory(100);

  //Resolution to read the potentiometer
  analogReadResolution(12);
}


void loop(){

  //Sample the potentiometer and cast into a 16-bits (15 fractional).
  int16_t pot1_val = (int16_t)(analogRead(pot1_pin) << 3);
  
  reverb.set_attenuation_factor(pot1_val);
  delay(10);
  
}

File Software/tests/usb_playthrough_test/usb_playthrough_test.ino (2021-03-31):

#include <Audio.h>


AudioInputUSB     usb1;
AudioOutputI2S    cs4344_dac;

//Simple pass through of the USB input audio to the DAC output.
AudioConnection   connection_1(usb1, 0, cs4344_dac, 0);

void setup() {
  // put your setup code here, to run once:
  AudioMemory(8);
}

void loop() {
  // put your main code here, to run repeatedly:

}

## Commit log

2020-10-23 ISC schematic design and ISC LTSpice simulation.
    [Input_Signal_Conditioner.kicad_pcb, Input_Signal_Conditioner.sch]
2020-10-23 Assigned PCB footprints to ISC. Started layout of the PCB, traces still need to be routed.
    [Input_Signal_Conditioner.kicad_pcb, Input_Signal_Conditioner.sch]
2020-10-28 Redesigned the ISC LPF filter to a new cutoff frequency. Also began documentation of the ISC design. Updated the LTSpice simulation of the ISC to reflect LPF changes. Choose an Op-amp for the design.
    [Input_Signal_Conditioner.kicad_pcb, Input_Signal_Conditioner.sch]
2020-10-29 Redid the layout of the PCB to be THT components. Layout needs review, then it is ready to print.
    [Input_Signal_Conditioner.kicad_pcb, Input_Signal_Conditioner.sch]
2020-10-30 Added mounting holes to the Input Signal Conditioner PCB. Also began citation information for ISC documentation.
    [Input_Signal_Conditioner.kicad_pcb, Input_Signal_Conditioner.sch]
2020-11-02 Made edits suggested by Mark to the ISC pcb. Sent the board for Milling.
    [Input_Signal_Conditioner.kicad_pcb, Input_Signal_Conditioner.sch]
2020-11-03 Designed the breakout board for the 10TSSOP footprint of the ADC and DAC. Needs review before manufacturing.
    [Breakout_10TSSOP.kicad_pcb, Breakout_10TSSOP.sch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]
2020-11-03 Revised PCB for the 10TSSOP Breakout board. Sent in for fabrication.
    [Breakout_10TSSOP-B_CrtYd.gbr, Breakout_10TSSOP-B_Cu.gbr, Breakout_10TSSOP-B_SilkS.gbr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]
2020-11-10 Updated an incorrect resistor value on the schematic (resistor R6).
    [Input_Signal_Conditioner.sch]
2020-11-11 Edited the LTSpice simulation to use th 22nF AC coupling capacitor.
2020-11-13 Started the schematic design of the DIGIMUSER Board, the final PCB design.
    [Digimuser_Board.kicad_pcb, Digimuser_Board.sch, Teensy_4.0_Assembly.STEP]
2020-11-13 Finished the electrical connections to the ADC on the schematic.
    [Digimuser_Board.sch]
2020-11-18 Added the DAC, Output Signal Conditioner, and 5V linear regulator.
    [Digimuser_Board.sch]
2020-11-19 Added the rotary switch and slider pot to the schematic. Created custom symbol for the rotary switch.
    [Digimuser_Board.sch]
2020-11-28 Assigned PCB footprints to all the components. Some components may need footprints revised.
    [Digimuser_Board.kicad_pcb, Digimuser_Board.sch]
2020-11-28 Started the PCB layout. Also had to find a new voltage regulator.
    [Digimuser_Board.kicad_pcb, Digimuser_Board.sch]
2020-11-28 Completed most of the PCB layout organization. Still have a lot of work on it.
    [Digimuser_Board.kicad_pcb, Digimuser_Board.sch]
2020-11-28 Continued PCB layout.
    [Digimuser_Board.kicad_pcb, Digimuser_Board.sch]
2020-11-29 Finished the first revision of the PCB layout. Needs reviewing.
    [Digimuser_Board.kicad_pcb, Digimuser_Board.sch]
2020-12-01 Last save before making circuit revisions.
    [Digimuser_Board.sch]
2020-12-01 Did a re-layout of the PCB and redid the schematic.Ready for review.
    [Digimuser_Board.kicad_pcb, Digimuser_Board.sch]
2020-12-02 Relabled Testpoints on PCB.
    [Digimuser_Board.kicad_pcb]
2020-12-02 Added pin connection for a second potentiometer.
    [Digimuser_Board.kicad_pcb, Digimuser_Board.sch]
2020-12-03 Sent board out for review. Received feedback and made changes to the PCB layout accordingly. Changes include: Pin headers spaced 0.1in, Labeling Teensy connection pins, updating voltage regulator GND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
    [Digimuser_Board.kicad_pcb, Digimuser_Board.sch]
2020-12-23 Finished final details for first prototype.
    [Digimuser_BOM_JLCPCB.xlsx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]
2021-02-01 Added a basic led_blink test code for testing the Teensy 4.0
2021-03-01 Wrote the CS4344 test sketch for the Teensy 4.0 to be used for Electrical validations that the DAC works.
2021-03-01 Wrote the cs5343_test sketch to test the cs5343 ADC works.
2021-03-13 Prototyped Custom effect structure. Compliles but is untested.
2021-03-13 Tested basic AmplifierEffects class. This proves how to structure custom effects to integrate with the Teensy4.0 audio lib.
2021-03-26 Reorganized the file structure to be cleaner. Made a simple iir comb filter based reverb in MATLAB.
2021-03-27 Wrote untested code for fixed-point based reverb using a single IIR Comb filter...needs testing and debugging.
    [Reverb.h]
2021-03-29 Got basic reverb working on the DIGIMUSER using fixed point
    [Reverb.h, Reverb.ino]
2021-03-29 Revised file structure...to run the examples, the DIGIMUSER folder must be in the Arduino/Libraries directory.
2021-03-29 Added the MIT license to the top of all the code. Finished writing the reverb effect with 4 IIR comb filters...needs testing.
2021-03-29 Got Reverb working very well with 4 IIR Comb filters.
2021-03-30 Sample the pot to 16-bits (15 fractional). This controls the attenuation factor for the IIR comb filters. Needs testing.
2021-04-02 Added the rotary switch test arduino sketch.

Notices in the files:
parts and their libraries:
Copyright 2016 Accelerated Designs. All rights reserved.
